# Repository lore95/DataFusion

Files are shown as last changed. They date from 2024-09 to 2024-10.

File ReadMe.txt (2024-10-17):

Project: ML Video Recognition & Pressure Boards for Post-Surgery Knee Rehabilitation @ KTH

INTRODUCTION
This project integrates machine learning-based video recognition and pressure boards to combine extrapolated data, generating an accurate 3D model of forces and human body movement. The main goal is to evaluate a patient's muscular power and movement fluidity, essential for monitoring progress in post-surgery knee rehabilitation.

PROBLEM STATEMENT
Evaluating muscle power and movement fluidity is crucial for tracking post-surgery recovery in patients with knee injuries. Traditionally, physiotherapists rely on qualitative assessments or expensive equipment to obtain reliable data. This project aims to provide a cost-effective, accurate, and universal solution for precise measurements through force sensors and skeleton tracking technology.

SOLUTION
Our system leverages data from four force sensors on a Wii board combined with video-based skeleton tracking to offer enhanced evaluations of knee recovery. By providing precise metrics, it complements and improves traditional methods of physiotherapy, offering a more data-driven approach to post-surgery rehabilitation.

HOW IT WORKS
Force Sensors: Four force sensors from a Wii board collect data on pressure distribution during movement.
Skeleton Tracking: Video-based skeleton tracking technology captures the movement and alignment of the patient's body.
Data Integration: Both sources of data are combined to create a 3D model that visualizes forces and motion, allowing for detailed analysis of knee recovery progress.

CONTRIBUTING
We welcome contributions! Please feel free to submit a pull request or raise an issue to discuss improvements or report bugs.

PROJECT STRUCTURE
Src/DataFusionExe
-DataFusion.py
	This file contains the code responsible for merging the data from the two core technologies used in this project: force sensors from the Wii board and video-based skeleton tracking. The integration of these datasets allows for the creation of a detailed and accurate 3D model, which is essential for evaluating a patient's post-surgery knee recovery.

-ImageRecognition AND PressureReadings:
	The folder ImageRecognition contains all the code related to skeleton tracking development and testing.
	The folder PressureReadings contains the implementation for reading force data from the Wii board's sensors.

-Requirements.txt
	The requirements.txt file lists all necessary dependencies for the project.

-yolov8m-pose.pt
	We use the yolov8m-pose.pt model for skeleton tracking.

INSTALLATION (WIP)
Clone the repository: git clone https://github.com/lore95/DataFusion.git
Install dependencies: pip install -r requirements.txt
Follow the steps in the Readme file located in PressureReadings
Run the application: python DataFusion.py

USAGE
Connect the Wii board to your USB port.
Start collecting data for post-surgery knee rehabilitation analysis.

The project communication channel: https://app.clickup.com/9012214187/v/b/s/90121097948

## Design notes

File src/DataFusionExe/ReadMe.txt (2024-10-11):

DATA INTEGRATION: FORCE SENSORS AND SKELETON TRACKING
This section contains the code responsible for merging the data from the two core technologies used in this project: force sensors from the Wii board and video-based skeleton tracking. The integration of these datasets allows for the creation of a detailed and accurate 3D model, which is essential for evaluating a patient's post-surgery knee recovery.

- The folder ImageRecognition contains all the code related to skeleton tracking development.
- The folder PressureReadings contains the implementation for reading force data from the Wii board's sensors.
- The script DataFusion.py integrates the data from both sources and runs the program.
- The requirements.txt file lists all necessary dependencies for the project.
- We use the yolov8m-pose.pt model for skeleton tracking.

INSTALLATION (WIP)
Clone the repository: git clone https://github.com/lore95/DataFusion.git
Install dependencies: pip install -r requirements.txt
Run the application: python DataFusion.py

USAGE
Connect the Wii board to your USB port.
Launch the video recognition system.
Start collecting data for post-surgery knee rehabilitation analysis.

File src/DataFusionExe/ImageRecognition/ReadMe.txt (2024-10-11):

IMAGE RECOGNITION APP

This section contains the code for developing the image recognition app used in this project. The app leverages machine learning models to detect and track specific body movements, contributing to the analysis of post-surgery knee rehabilitation. The image recognition system is designed to provide accurate and real-time data on the patient's movement, which is integrated with force sensor data for a comprehensive evaluation.

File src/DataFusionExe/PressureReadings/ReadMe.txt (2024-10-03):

# Project Title: Wii Balance Board Data Reading

This project contains code for connecting and reading data from the Wii Balance Board using RISC-V based microcontroller boards.

## Description

In this repository, you will find tools to connect the Wii Balance Board to your laptop, capture sensor data, and analyze it. The project includes code for setting up the board, reading sensor data, and processing the data for visualization and analysis.

## Getting Started

### Prerequisites

Before you begin, ensure you have the following installed on your system:

- A Windows-based laptop
- RISC-V toolchain installed (Instructions below)
- PowerShell

### Dependencies

For proper functionality, the Wii Balance Board must be connected to your laptop via USB. The following dependencies are required:

- RISC-V toolchain setup for development
- PowerShell for running commands

### Installing the Drivers

Follow these steps to install the required drivers and development environment:

1. Install the RISC-V based microcontroller toolchain by following the instructions provided here: [KTH Development Environment Setup](https://canvas.kth.se/courses/19538/pages/install-development-environment)
2. After reaching step 3 in the instructions, navigate to `/toolchain-gd32v/projects/wiiboard`.
3. Compile the `main.c` file by following step 5 in the guide.
4. This process will complete the connection setup between the Wii Balance Board and your laptop.

### PowerShell Setup (For Windows Users)

Once the drivers are installed, use the following PowerShell commands to verify the correct COM port and read data from the Wii Balance Board:

1. Open PowerShell.
2. Run the following commands to detect the COM port:
   - Disconnect the USB cable.
   - Run:
     ```powershell
     [System.IO.Ports.SerialPort]::getportnames()
     ```
   - Reconnect the USB cable and run the command again. The new COM port listed is your board’s port name.
3. Note the COM port name (e.g., "COM6").

To start reading data from the board:

1. Open PowerShell and run these commands one by one:
    ```powershell
    $portName = "COM6"
    $baudRate = 9600
    $serialPort = New-Object System.IO.Ports.SerialPort $portName, $baudRate, None, 8, One
    $serialPort.Open()
    try {
        while ($true) {
            if ($serialPort.BytesToRead -gt 0) {
                $data = $serialPort.ReadLine()
                Write-Host $data
            }
            Start-Sleep -Milliseconds 100  # Delay to avoid excessive CPU usage
        }
    } catch {
        Write-Error "An error occurred: $_"
    } finally {
        $serialPort.Close()
        Write-Host "COM port closed."
    }
    ```
2. If data is displayed, the setup is successful.

### Executing the Program

You can use the following scripts to process and analyze the data:

- `/toolchain-gd32v/projects/wiiboard/data_read.py`: This script reads and plots sensor data, saving the output to a JSON file.
- `/toolchain-gd32v/projects/wiiboard/sensor_data/sensitivity.py`: This script calculates the relationship between the sensor readings and the weight applied to the Wii Balance Board sensors.

## Common Issues

If you encounter problems:

1. **COM Port Not Detected:** Ensure the USB connection is secure and verify that you are using the correct COM port.
2. **No Data Output:** Check the power to the board and verify that the PowerShell commands are running without errors.

## Contact

For help or advice, please reach out to the contributors.

## Authors

Marwan Zarouf

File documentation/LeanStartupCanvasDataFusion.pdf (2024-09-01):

Problem

•Athletes can measure either force or motion, but not both simultaneously
•Current techonologies are extremely expensive

Existing Alternatives

•GIH or similar Labs (hard to access)
•Marker video recognition
•High cost pressure boards

Solution

•Integrate an affordable force measurement using a new chip on the market and a solution with a marker less motion
analysis system

Key Metrics

- Accuracy of force
measurements
- Accuracy of body
recognition through video
- Analysis of force vectors in conjunction with motion
tracking

Unique Value Proposition

- An affordable system that enables athletes and
coaches to measure and
analyze movements from
both a motion and force
perspective

High Level Concept

- Your personal
biomechanical and force
analysis built in for your training

Unfair Advantage

- Proprietary Software
- Costs

Channels

- Low budget sport teams
- Government Sporting
Agencies
- Gyms
- Phisiotherapy / Health
- B2C

Customer Segments

- Athletes / Coaches
- Physiotherapists
- Orthopedists

Early Adopters

- People interested on their performance, strength,
movement fluidity

Cost Structure

- Wii boards / Force sensor
- Chips CS1237
- Camera
- Server mainteinance*
- Hardware needed
- Commercialization / Ads

Revenue Streams

- Product sales
- Monthly subscription for analysis

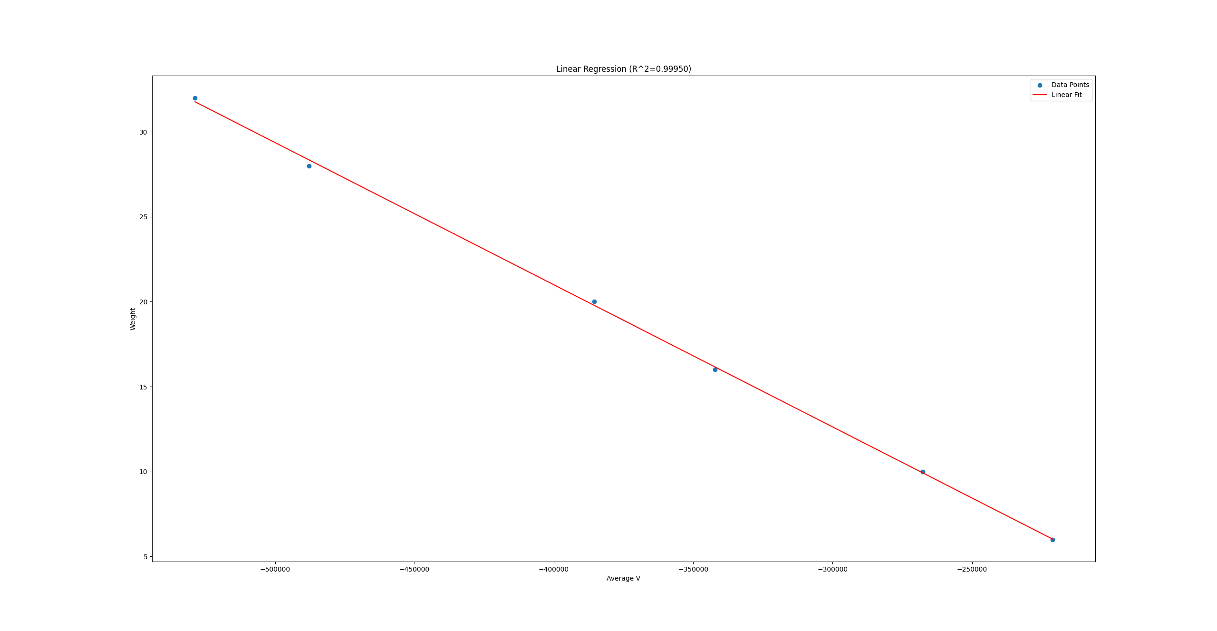
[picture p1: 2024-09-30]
src/DataFusionExe/PressureReadings/project/regressions/V4_40_128.png

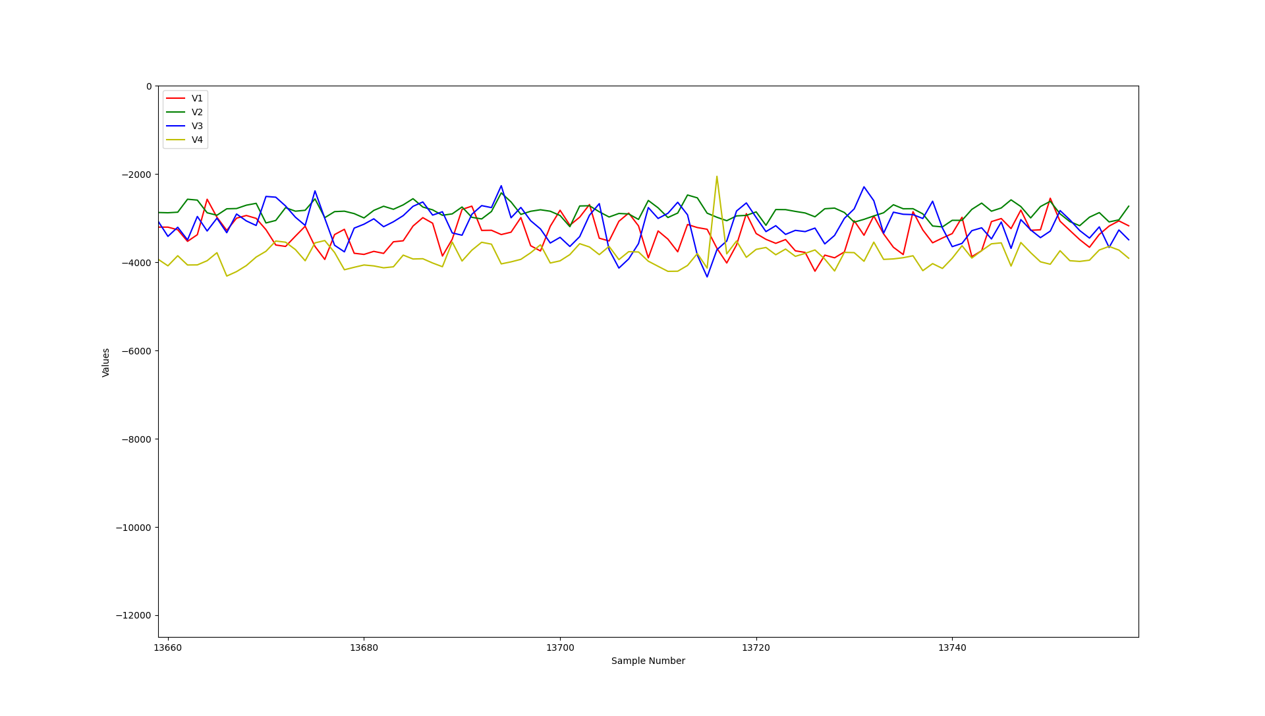
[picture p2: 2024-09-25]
src/DataFusionExe/PressureReadings/project/toolchain/projects/wiiboard/good.png

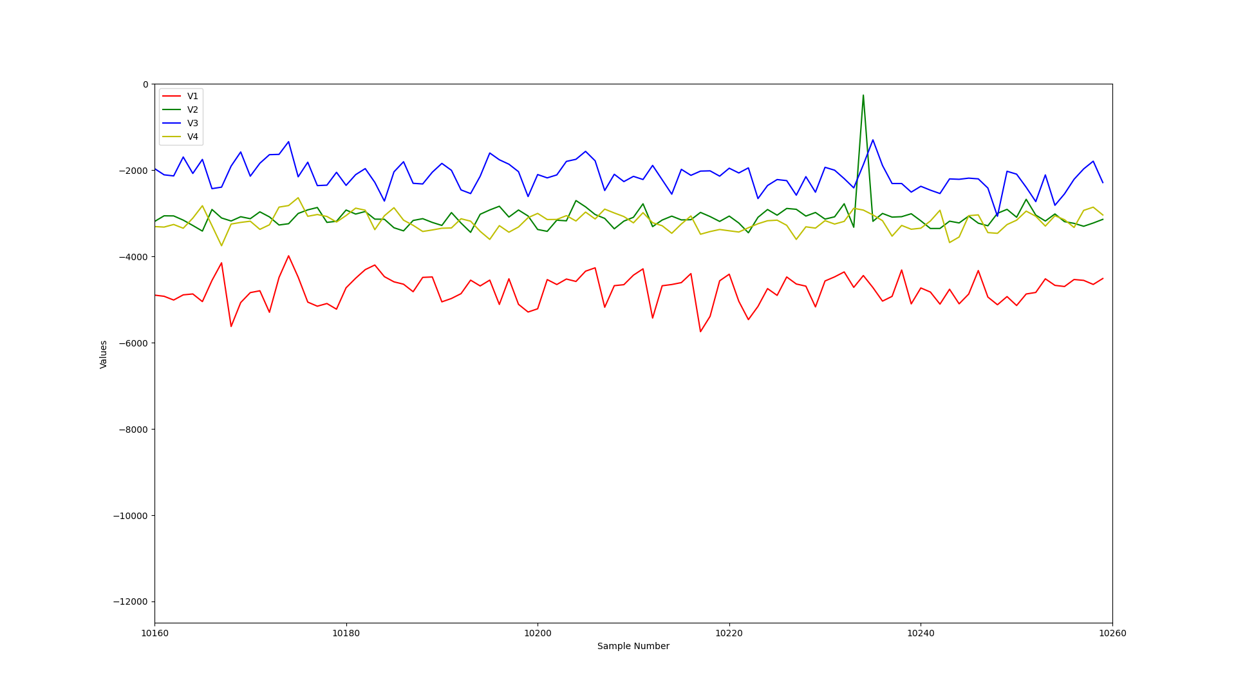
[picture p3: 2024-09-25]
src/DataFusionExe/PressureReadings/project/toolchain/projects/wiiboard/example.png

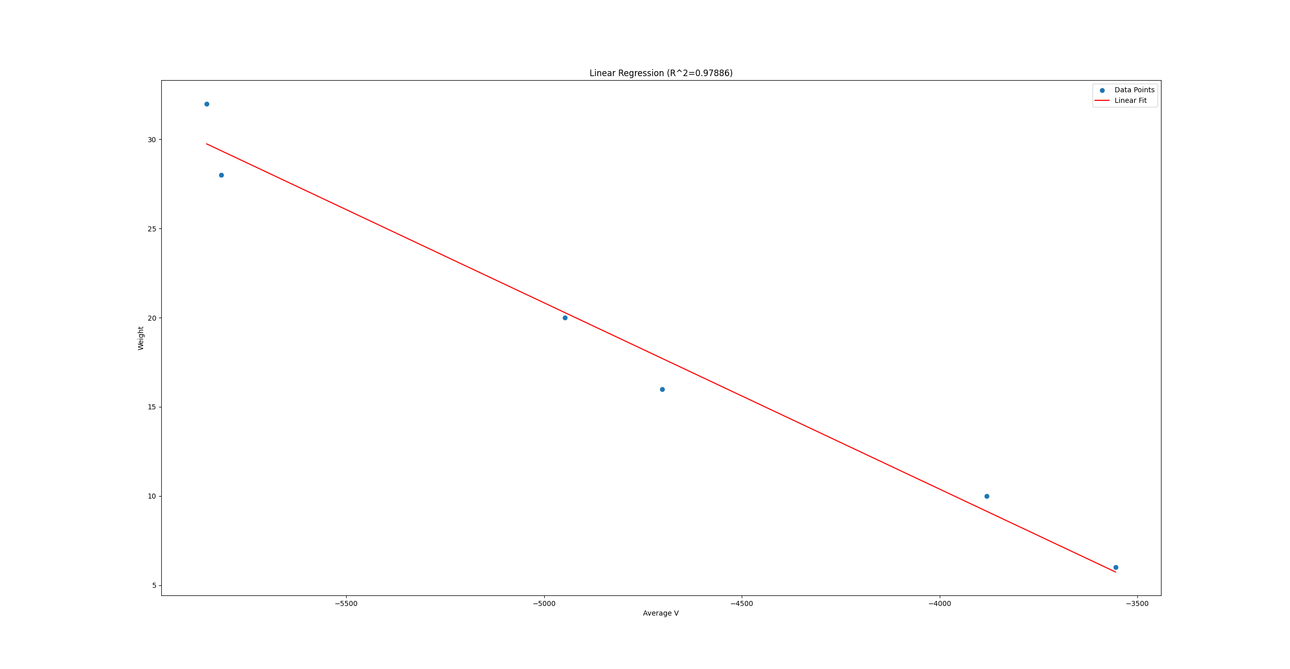
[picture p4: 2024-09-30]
src/DataFusionExe/PressureReadings/project/regressions/V1_40_1.png

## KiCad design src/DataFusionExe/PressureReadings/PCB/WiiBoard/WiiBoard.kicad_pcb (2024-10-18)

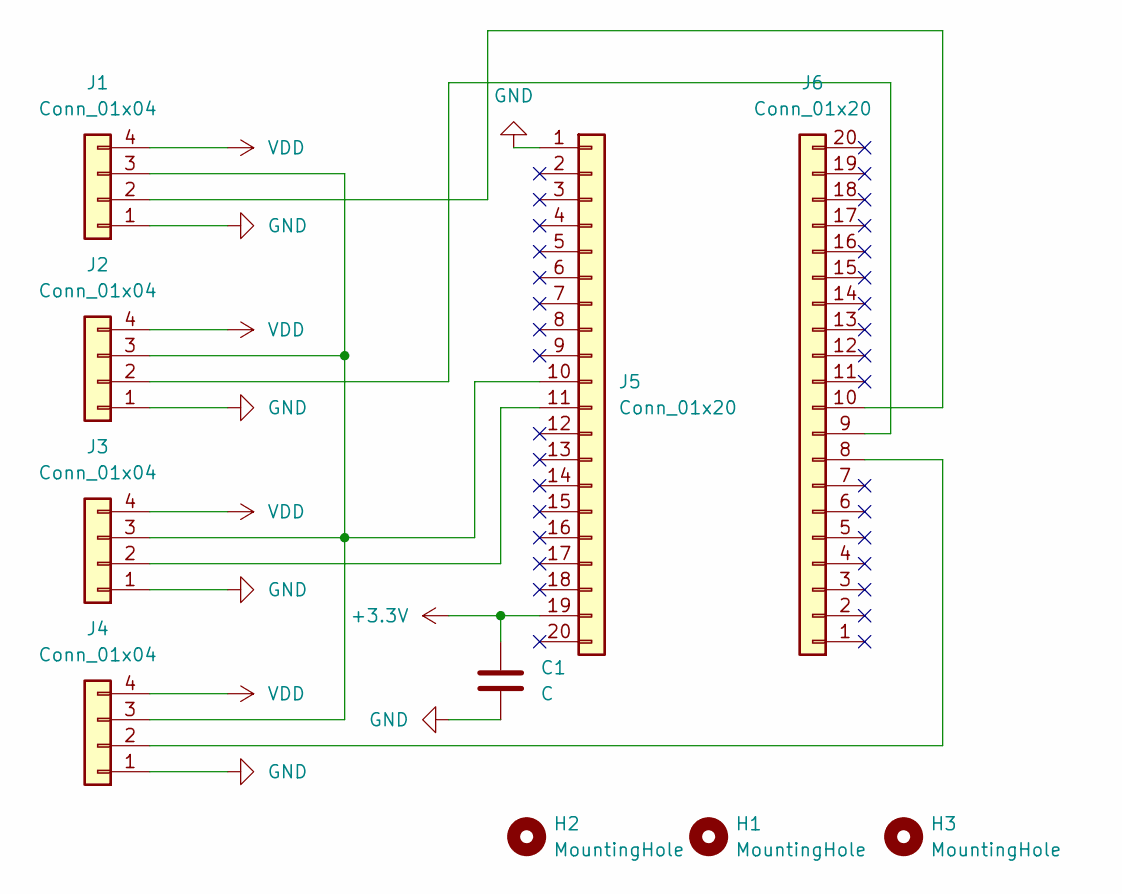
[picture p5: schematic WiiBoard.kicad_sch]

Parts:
C1: C; CP_Radial_D8.0mm_P5.00mm
H1, H2, H3: MountingHole; MountingHole_3.2mm_M3
J1, J2, J3, J4: Conn_01x04; PinSocket_1x04_P2.54mm_Vertical
J5, J6: Conn_01x20; PinSocket_1x20_P2.54mm_Vertical

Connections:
+3.3V: C1.1, J5.19
GND: C1.2, J1.1, J2.1, J3.1, J4.1, J5.1
unnamed: J1.2, J6.10
unnamed: J1.3, J2.3, J3.3, J4.3, J5.10
unnamed: J2.2, J6.9
unnamed: J3.2, J5.11
unnamed: J4.2, J6.8
VDD: J1.4, J2.4, J3.4, J4.4

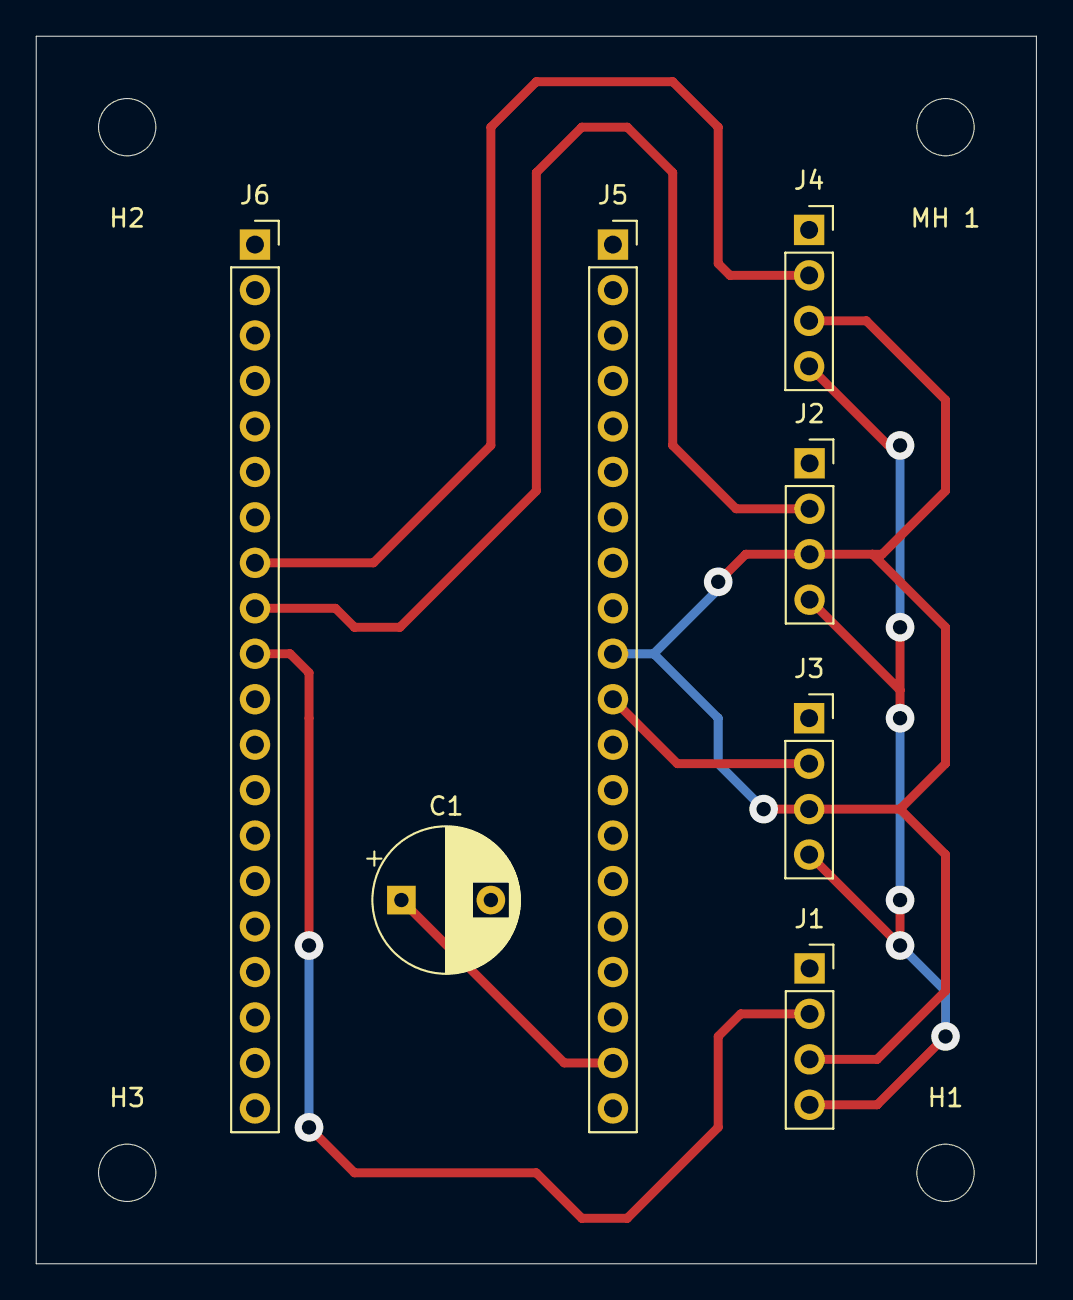
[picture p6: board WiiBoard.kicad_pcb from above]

Board: 2 copper layers, 55.9 x 68.6 mm, 11 parts (0 on the bottom side), 8 nets.

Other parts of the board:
MH 1: MountingHole; MountingHole_3.2mm_M3

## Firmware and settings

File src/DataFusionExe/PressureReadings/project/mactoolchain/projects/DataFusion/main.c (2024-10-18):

/* 
Replace this file with your code. Put your source files in this directory and any libraries in the lib folder. 
If your main program should be assembly-language replace this file with main.S instead.

Libraries (other than vendor SDK and gcc libraries) must have .h-files in /lib/[library name]/include/ and
.c-files in /lib/[library name]/src/ to be included automatically.
*/

#include "gd32vf103.h"
#define BITMASK 0xFFFFFFF8

int main(){
	uint32_t port = 0;
	uint32_t count = 0;
	rcu_periph_clock_enable(RCU_GPIOB);
	gpio_init(GPIOB, GPIO_MODE_OUT_PP, GPIO_OSPEED_50MHZ, GPIO_PIN_0 | GPIO_PIN_1 | GPIO_PIN_2);
	while(1){
		count += 1;
		port = gpio_input_port_get(GPIOB);
		gpio_port_write(GPIOB, (port & BITMASK) | (count & (~BITMASK)));
		for(volatile int i = 0; i < 1000000; i++);
	}
}

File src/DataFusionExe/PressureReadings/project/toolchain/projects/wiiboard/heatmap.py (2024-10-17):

import serial
import matplotlib.pyplot as plt
import matplotlib.animation as animation
import re
import numpy as np
from scipy.ndimage import zoom
from collections import deque
import datetime
import os


# Configure the serial connection
ser = serial.Serial(
    port='COM6',         # Set to the appropriate COM port
    baudrate=9600,       # Adjust to match your device's baud rate
    parity=serial.PARITY_NONE,
    stopbits=serial.STOPBITS_ONE,
    bytesize=serial.EIGHTBITS,
    timeout=1            # Timeout for reading (in seconds)
)

# Create a figure and axis for the heatmap
fig, ax = plt.subplots()
vmin = -1000000
vmax=0
# Initialize the 2x2 matrix for the heatmap (this represents the four sensor values)
heatmap_data = np.zeros((2, 2))

# Create the heatmap with initial data, using the full range of vmin to vmax0
# Using interpolation 'bilinear' to smooth the transitions
heatmap = ax.imshow(heatmap_data, cmap='hot', interpolation='bilinear', vmin=vmin, vmax=vmax)

# Set colorbar for reference
cbar = plt.colorbar(heatmap)
cbar.set_label('Force Value')

# Queues to store recent data points for smoothing (Moyenne glissante sur 10 dernières valeurs)
window_size = 10
v1_history = deque(maxlen=window_size)
v2_history = deque(maxlen=window_size)
v3_history = deque(maxlen=window_size)
v4_history = deque(maxlen=window_size)



def init():
    """Initialize the plot (heatmap)."""
    heatmap.set_data(np.zeros((2, 2)))  # Initialize with zeros
    return [heatmap]

def update(frame):
    """Update the heatmap with new sensor values."""
    line = ser.readline().decode('utf-8').strip()
    match = re.match(r'Time:\d+,V1:(-?\d+),V2:(-?\d+),V3:(-?\d+),V4:(-?\d+)', line)
    if match:
        v1, v2, v3, v4 = map(int, match.groups())

        print(datetime.now())
        # Clamp values to the range (vmin to 10000) to avoid extreme values affecting the plot
        v1 = np.clip(v1, vmin, vmax)
        v2 = np.clip(v2, vmin, vmax)
        v3 = np.clip(v3, vmin, vmax)
        v4 = np.clip(v4, vmin, vmax)
        # Add the new values to the history deque
        v1_history.append(v1)
        v2_history.append(v2)
        v3_history.append(v3)
        v4_history.append(v4)

        # Compute the moving average for each sensor
        v1_avg = np.mean(v1_history)
        v2_avg = np.mean(v2_history)
        v3_avg = np.mean(v3_history)
        v4_avg = np.mean(v4_history)

        # Clamp values to the range (vmin to vmax)
        v1_avg = np.clip(v1_avg, vmin, vmax)
        v2_avg = np.clip(v2_avg, vmin, vmax)
        v3_avg = np.clip(v3_avg, vmin, vmax)
        v4_avg = np.clip(v4_avg, vmin, vmax)

        # Update the heatmap data (2x2 matrix representing the four sensors)
        heatmap_data[0, 0] = v1_avg  # Top-left
        heatmap_data[0, 1] = v2_avg  # Top-right
        heatmap_data[1, 0] = v3_avg  # Bottom-left
        heatmap_data[1, 1] = v4_avg  # Bottom-right


        # Smooth the heatmap by interpolating the 2x2 grid to a larger grid (e.g., 100x100)
        smoothed_heatmap = zoom(heatmap_data, zoom=3)  # Adjust the zoom factor as needed for smoothness

        # Update the heatmap display
        heatmap.set_data(smoothed_heatmap)
        print(datetime.now())

        return [heatmap]
        
# Set up animation to continuously update the heatmap
ani = animation.FuncAnimation(fig, update, init_func=init, blit=True, interval=0.1)

plt.show()

# Close the serial port after closing the plot window
ser.close()

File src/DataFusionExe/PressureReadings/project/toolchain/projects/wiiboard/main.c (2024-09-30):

#include "gd32vf103.h"
//USB includes
#include "usb_serial_if.h"
#include "usb_delay.h"

//ADC includes
#include "cs1237.h"
#include "cs1237_port.h"

//Utils
#include <stdlib.h>
#include <string.h>

//Need to be defined for usning USB-printf
#define USE_USB
#define USE_USB_PRINTF

//How many ADCs that will be used
#define N_ADCS 4

int main(void)
{
    //Timekeeping for performance metrics
    uint64_t time = 0;
    uint64_t last_time = 0;
    uint32_t delta_time = 0;
    uint64_t delta_seconds = 0;
    uint64_t time0 = get_timer_value();

    //Pin assignments for CS1237 chips, clock pin is shared by all chips
    cs1237_channel_t clock_pin;
    clock_pin.pin = GPIO_PIN_0;
    clock_pin.port = GPIOB;
    clock_pin.rcu = RCU_GPIOB;

    //Data pin assignments, one for each chip in use
    cs1237_channel_t data_pins[N_ADCS];
    //All pins are on the same port, but does not have to be
    for(int i = 0; i < N_ADCS; i++){
        data_pins[i].port = GPIOB;
        data_pins[i].rcu = RCU_GPIOB;
    }
    //One data pin for each ADC
    data_pins[0].pin = GPIO_PIN_1;
    data_pins[1].pin = GPIO_PIN_7;
    data_pins[2].pin = GPIO_PIN_8;
    data_pins[3].pin = GPIO_PIN_9;

    //USB setup, puts out a virtual COM port, once setup printf() is available for sending over USB
    uint8_t usb_data_buffer[512] = {0};
    configure_usb_serial();
	while(!usb_serial_available())usb_delay_1ms(100);
	usb_delay_1ms(1000);
    printf("USB connected...\r\n\r");
    usb_delay_1ms(1000);

    //Initialize ADCs
    cs1237_port_initialize_pins(N_ADCS, data_pins, clock_pin);
    usb_delay_1ms(100);

    //Configure samplerate and gain of the ADCs
    //10, 40, 640 and 1280 SPS available
    //Higher the SPS, higher it will be noise
    //Same for gain, gain is useful for getting the wider range available
    //1(0dB), 2(6dB), 64(36dB), 128(42dB) gain available
    //Refer to datasheet for how each setting affects accuracy
    cs1237_sample_rate_and_gain(CS1237_640SPS, CS1237_GAIN128, N_ADCS, data_pins);
    while(1){
        //Wait for new data to be available, polled
        while(!cs1237_data_ready(N_ADCS, data_pins));
        //Read ADC samples (from all initialized ADCs)
        cs1237_read(N_ADCS, data_pins);

        //Measure time between each sample (to measure jitter)
        //delta time value in seconds is delta_time/24,000,000
        //For sample rate in Hz => 1/delta_seconds
        time = get_timer_value() ;
        delta_time = time - last_time;
        last_time = time;
        delta_seconds = delta_time/24000;

        //Print measured data
        printf("Time:%d,V1:%d,V2:%d,V3:%d,V4:%d\r\n\r", delta_time, data_pins[0].value, data_pins[1].value, data_pins[2].value, data_pins[3].value);
        fflush(0);
    }
}

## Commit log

2024-08-29 Changed clickuplink to go to board
2024-09-25 calibration data process
2024-10-08 Fixed pathing and folder names, added skeleton tracking
    [DataFusion.py]
2024-10-08 Canhged Pressure Readings folder path
2024-10-08 changed dir name for pressure
2024-10-11 PCB Board
    PCB First design, not fully done but great advance
    [WiiBoard.kicad_pcb, WiiBoard.kicad_sch]
2024-10-17 PCB Corrections
    [WiiBoard.kicad_pcb, WiiBoard.kicad_sch]
2024-10-17 added filtered force value
